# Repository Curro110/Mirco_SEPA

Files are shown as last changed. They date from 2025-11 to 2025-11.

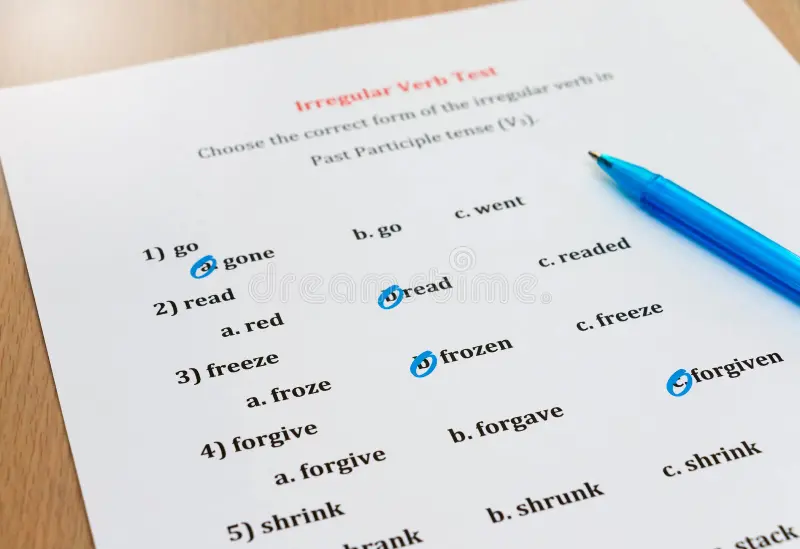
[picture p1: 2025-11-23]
Planos/examen-inglés-en-la-tabla-85873785.webp

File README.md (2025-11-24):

# Micro_SEPA Guia de instalación
Este documento explica cómo configurar el microcontrolador y la API de WhatsApp (CallMeBot) para el correcto funcionamiento del proyecto.
Siga los pasos cuidadosamente, ya que la configuración no es trivial.
1. Activación del Bot de WhatsApp
Agregue el número de teléfono +34 621 33 17 09 en sus contactos con el nombre PastilleroBot.
2.	En WhatsApp busque el contacto y escríbale ```I allow callmebot to send me messages``` esto activará el bot para que reconozca su número de teléfono.
3.	 Mandará un mensaje con una apikey a su número de teléfono el cual deberá copiar para poder configurar el programa.
4.	 Abra Arduino IDE e instale el paquete de board de ESP32 y en librerías instale también UrlEndoce de Masayuki.
5.	En esta parte de código sustituya su ssid por el nombre de su wifi y la contraseña de esta, aparte copie y pegue su apikey y ponga el número de teléfono donde recibirá los mensajes.
 ```
const char* ssid = "NOMBRE_DE_TU_WIFI";
const char* password = "CONTRASEÑA_DE_TU_WIFI";

String apiKey = "TU_API_KEY";
String phoneNumber = "34XXXXXXXXX";  // Prefijo + número, sin el símbolo +
```
Al arrancar el programa debera salir un mensaje por WhatsApp diciendo que esta conectada la esp32.

6.   Conenecte los pines del Micro alos pines de la esp32 como muestra el esquema.
   
| Micro | ESP32 |
| ----- | ----- |
| K6 | 4 |
| K7 | 5 |
| H0 | 18 |

7.  Conecte lo siguiente en el Micro:

  El BoosterPack de servos.

  La pantalla (parte superior del Micro).

  Los servos a los terminales S1, S2 y S3.

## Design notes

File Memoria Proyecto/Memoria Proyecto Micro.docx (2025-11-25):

Proyecto de Sistemas Electrónicos para Automatización (Microcontroladores)

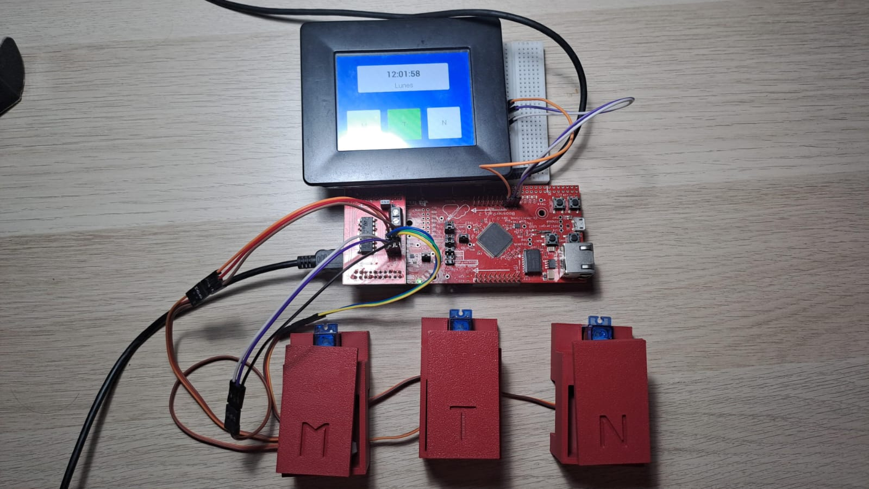
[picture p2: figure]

# 1. Introducción:

La idea central del proyecto se cimenta sobre una pregunta clave: ¿cómo se puede hacer la vida de las personas mayores más sencilla? Con el paso del tiempo, es común que las personas mayores necesiten responsables que lleven el registro de su salud. En particular la ingesta de medicamentos puede convertirse en un reto, ya sea por problemas de memoria o estado físico en general.

A partir de esta necesidad nace el proyecto de PEPA (Pastillero electrónico Programable y automático). Un proyecto diseñado para facilitar y automatizar la administración de medicamentos mediante indicadores acústicos y un sistema pastillero con servomotores. En su desarrollo se aplican los conocimientos aprendidos en las sesiones teóricas y prácticas de la asignatura, además de un exhaustivo trabajo de investigación por parte de los integrantes del proyecto.

# 2. Objetivos:

- Monitorización y registro de las pastillas tomadas en el día.
- Realización de interfaz asequible y practica para todos los públicos.
- Comunicación externa vía wifi con responsable o con propio usuario.
- Reprogramación de la toma de pastillas.
- Crear un sistema que funcione a lo largo del tiempo, siempre que esté conectado.

# 3. Enfoque Práctico

Este pastillero tiene las siguientes características:

La toma de pastillas se hará con una diferencia de 6h entre pastilla y pastilla de forma predeterminada. A no ser que el usuario programe lo contrario.

En la primera conexión del micro, se le pedirá al usuario añadir manualmente el día y hora mediante comunicación por puerto serie. Para posteriormente preguntar sobre la ingesta o no de la pastilla asignada a esa franja horaria, con el fin de llevar una monitorización desde el momento que se enciende el micro hasta que se desee apagarlo.

Avisa de cuando debe de tomar la pastilla mediante indicadores acústicos, a la hora deseada por el usuario o por la predeterminada por el programa.

Además, si se pospone la alarma y no se toma la pastilla en una franja de tiempo predeterminada, se generará un mensaje WhatsApp que avisará al mismo usuario del pastillero o a un familiar que este a cargo, la no ingesta de la pastilla.

En caso de activar tarde el micro (y por consecuente no haber registrado la toma de una pastilla) o de haber cancelado la alarma; el usuario podrá abrir manualmente la compuerta del pastillero necesario.

Al finalizar la toma de pastillas del día se ruega al usuario recargar manualmente los pastilleros mediante petición de una tecla por puerto serie, en caso contrario se saltará a este estado a una hora en concreto con el fin de poder preservar el funcionamiento del pastillero.

# 4. Resumen Programas

## 4.1 Programa de microcontrolador TIVA

Se integra una primera fase de interacción con el usuario por UART, donde se le pide rellenar la fecha y hora exacta del día. Es recomendable que esta parte sea realizada por el adulto a cargo, ya que el control del teclado puede ser enrevesada para el abuelo.

Luego, se realiza una interfaz gráfica con la FT800 donde se integran una serie de pantallas que guían de forma lógica al usuario a lo largo del proceso: pantalla de inicio, pulsadores de alarmas…

Aparte se integra una comunicación externa mediante salidas de periféricos GPIO con una ESP32 para el mensaje de WhatsApp.

## 4.2 Programa de ESP32

Se ha realizado un programa en paralelo con Arduino IDE, donde se programa la ESP32 a WIFI y el servicio de una API de WhatsApp llamada CallMeBot. Este programa realiza una primera conexión al WIFI suministrado con su SSID y su contraseña, luego una segunda conexión al servidor de la API y por último manda un mensaje WhatsApp dependiendo de las señales de entrada obtenidas por el puerto GPIO.

# 5. Realización de los programas:

## 5.1 Programa Micro

El programa implementa el control completo de un dispensador automático de pastillas con tres tomas diarias: mañana, tarde y noche. El sistema integra una pantalla táctil FT800, tres servomotores que abren cada compartimento de pastillas, y dos módulos ESP para enviar avisos o recordatorios mediante comunicación UART.

Los periféricos que se han habilitado son:

- Puerto K y H: GPIO para la comunicación con la ESP32.
- 3 módulos PWM para el mover los pastilleros mediante servos.
- UART para comunicación inicial de configuración de la fecha y marcar la recarga de las pastillas.
- Timer0 que habilita las interrupciones cada 20 ms.
- Timer1 que genera un parpadeo para las funciones de alarma.
- Pantalla FT800 inicializada mediante SPI, utilizada para dibujar la interfaz y registrar las pulsaciones táctiles de los botones.

En cuanto al funcionamiento principal del proyecto, se realiza mediante una máquina de estados switch(estado_actual):

- Inicio:

Este estado inicial pide al usuario por pantalla de introducir la fecha mediante UART. La introducción de la fecha es bastante robusta, pudiendo retroceder si el usuario se ha equivocado de carácter o incluso detectar si los caracteres introducidos no son correctos. Luego, se pasa directamente al siguiente estado de configuración.

- Dia1, Dia2, Dia3, Verificacion_dia, Hora1, Hora2, Verificacion_hora, Min1, Min2, Verificacion_min:

Esta serie continua de estados sirve para obtener mediante UART: el día de inicialización del micro, introduciendo las 3 primeras letras del día; la hora y el minuto, teniendo que añadir 2 dígitos (de 00 a 23 para la hora y de 00 a 59 para el minuto), y por último la verificación de que estos estén correctos.

Una vez introducida la hora, el programa redirecciona al usuario según la franja horaria en la que se encuentra: de 6 hasta las 12 será por la mañana, de 12 a las 18 será por la tarde y de las 18 hasta las 00 será por la noche. Esto se hace ya que el programa para inicializarse necesita saber en qué momento del día esta.

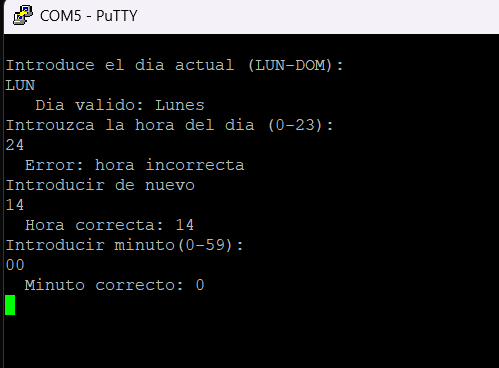
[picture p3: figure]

- Reposo1, Reposo2, Reposo3:

Como se ha explicado anteriormente, los estados de Reposo marcan si el usuario esta por la mañana, por la tarde o por la noche.

Aparte, se pregunta por pantalla si se ha tomado la pastilla que corresponde a la franja horaria en la que se encuentra el usuario.

En caso de haber tomado dicha pastilla, el usuario pasará al estado de confirmación de la hora: MananaOK, TardeOK, NocheOK.

De lo contrario, el programa redirecciona al usuario a la pantalla principal Inicio_i, donde se mostrará visualmente el pulsador de la pastilla que no se ha tomado en rojo.

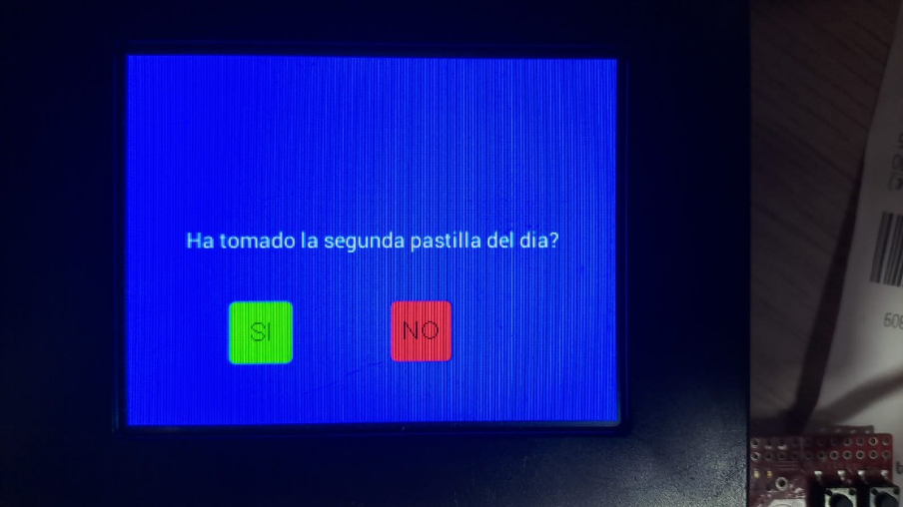
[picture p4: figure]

- MananaOK, TardeOK, NocheOK:

En este estado, se pregunta al usuario por pantalla la hora en la que se tomó la pastilla correspondiente a su franja horaria, mediante una interfaz interactiva donde el usuario puede aumentar o disminuir las horas y los minutos gracias unas flechas integradas por pantalla.

Una vez seleccionada la hora, se recalcula la toma de las siguientes pastillas (diferencia predeterminada de 6h entre pastilla y pastilla). Una vez finalizado se pasa al estado base de la interfaz llamado Inicio_i, donde se mostrará visualmente el pulsador de la pastilla que se ha tomado en verde.

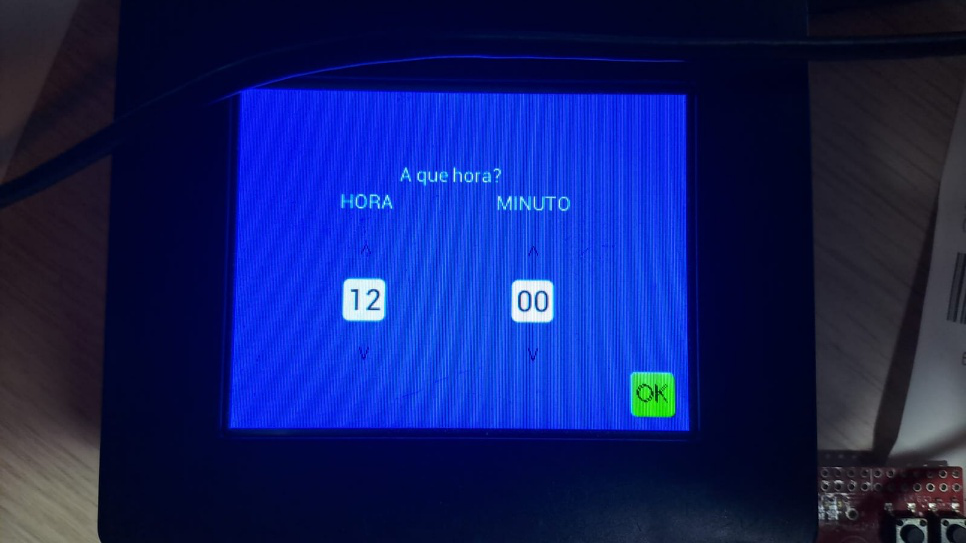
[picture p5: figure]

- Inicio_i

Este estado representa la interfaz principal del programa.

La parte superior marca el día, además de un reloj que marca el paso de las horas, minutos y segundos.

La parte inferior aparecen unos botones M, T, N que estarán de un color u otro según en qué estado se encuentre el programa: en rojo si la pastilla de esa franja horaria no se ha tomado, en verde para el caso contrario, o en blanco en caso de aun tener que programar la alarma de la pastilla correspondiente a esa franja horaria.

Si se quiere cambiar la hora programada de las pastillas o abrir el pastillero (en caso de no haber tomado la pastilla), el usuario pulsará el botón correspondiente a la franja horaria que se requiera, pasando a los estados llamados Manana, Tarde, Noche.

Si se inicia las alarmas de las pastillas, se saltará a los estados correspondientes de las alarmas: AlarmaManana, AlarmaTarde, AlarmaNoche. Las alarmas podrán saltar en cualquier momento de la interacción con la interfaz o de los siguientes estados, guardando en una variable estado_anterior el estado anterior previo a la alarma, pudiendo volver a el una vez apagada o cancelada.

Aparte este estado nos sirve de comunicación con la esp32 encendiendo los pines K6 y K7 y H1, que mandaran una señal en alto si no se ha tomado la pastilla en un tiempo preinstalado (para simplificar se ha puesto unos 10 segundos, pero podría ser perfectamente configurado).

Por último, se permite al usuario recargar el pastillero manualmente, en el caso de que la última pastilla se haya tomado (no_noche=0) y que se apriete la tecla ‘r’ o ‘R’ por puerto serie, saltando al estado Recarga. En el caso que el usuario no decida recargar, ya sea por olvido o por incapacidad, a partir de una hora predeterminada de la noche se saltará a dicho estado.

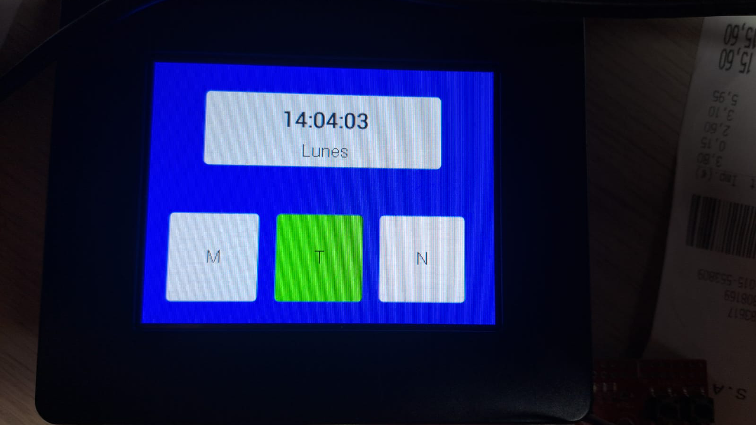
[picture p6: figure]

- Recarga, Fin_Recarga:

En este estado se permite al usuario recargar manualmente.

Se muestra tanto por pantalla como por puerto serie un aviso de recarga para el usuario, avisando de las teclas a pulsar para la debida recarga. En este caso, si se manda por UART los caracteres m, t y n, se abrirán los respectivos pastilleros, permitiendo su recarga.

Cuando el usuario plazca, puede enviar de nuevo por puerto serie la tecla f para finalizar el proceso, donde se cerrarán los pastilleros de uno en uno. Posteriormente se vuelve al estado Inicio_i, continuando con el correcto funcionamiento del programa.

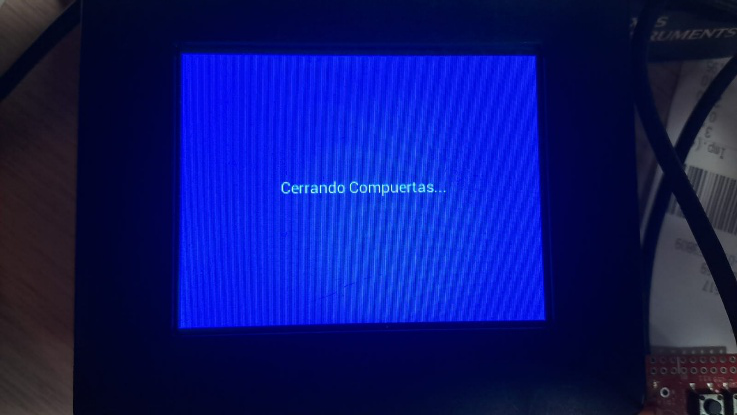
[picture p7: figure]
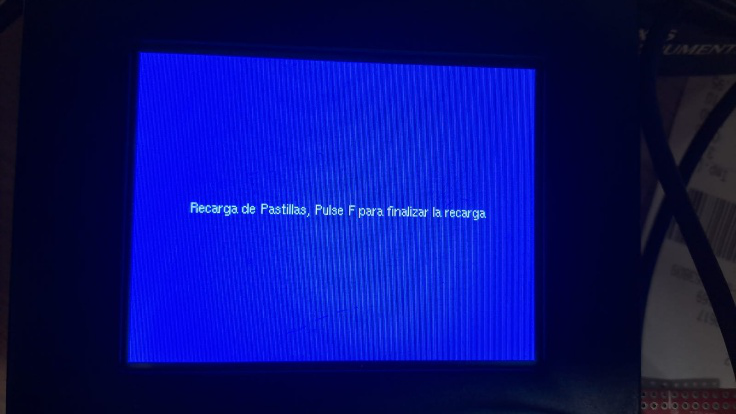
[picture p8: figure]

Este estado de interacción con el usuario es recomendable que sea realizada por el adulto a cargo, ya que puede suponer demasiado complicado para el abuelo.

- Manana,Tarde,Noche:

En estos estados se despliega una pantalla donde se muestra un botón para abrir el pastillero manualmente, un botón para editar la alarma correspondiente y un botón de cancelación en caso de querer volver a la pantalla inicial Inicio_i.

El botón para abrir manualmente el pastillero estará en gris o en verde según se deje o no abrir. Es decir, que se haya cumplido el tiempo para tomar la pastilla o que no se haya tomado en un primer momento. En caso de estar disponible se saltaría a los siguientes estados según la franja horaria en la que se encuentre el usuario: AbrirManana, AbrirTarde, AbrirNoche.

En cuanto al botón para configurar la hora de la alarma, en este se representará la hora predeterminada o programada por el usuario. En caso de querer modificar la alarma y pulsar el botón, se pasará a los siguientes estados de configuración: configHora1,2 o 3.

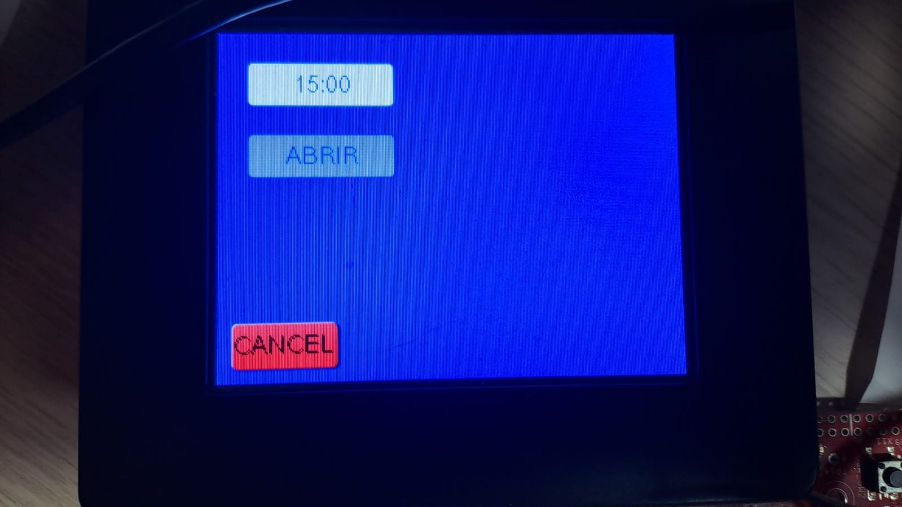
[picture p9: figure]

- AbrirManana, AbrirTarde, AbrirNoche:

Para acceder a estos estados el usuario debe:

- Haber cancelado la alarma. En ese caso, se le permite abrir manualmente la compuerta del pastillero.

-No haber tomado la pastilla correspondiente, una vez inicializado el micro.

Dentro de los estados, se abren las cajetillas mandando señales de PWM a los servos durante 5 segundos. Aparte aparece un mensaje por pantalla indicando al usuario que puede recoger su pastilla.

Una vez finalizada la recogida, se vuelve a la interfaz principal Inicio_i.

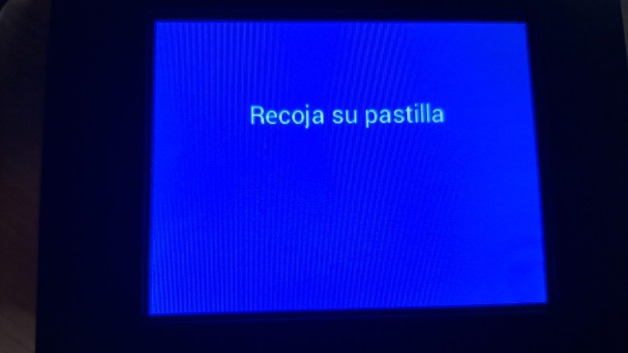
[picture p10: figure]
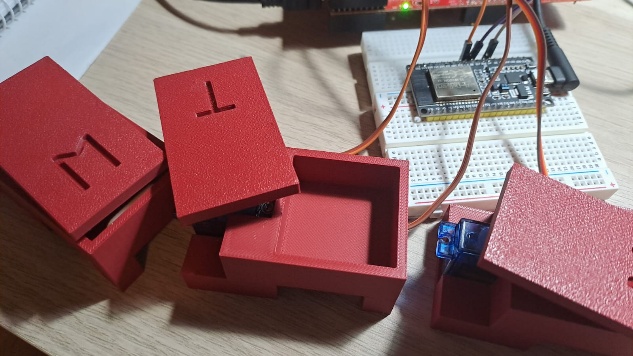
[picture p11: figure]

- ConfigHora1, ConfigHora2, ConfigHora3:

En estos estados, se despliega una pantalla en donde el usuario puede aumentar o disminuir las horas y los minutos gracias unas flechas integradas por pantalla.

No obstante, hay un rango de operación de 6 horas, es decir, el usuario no podrá programar la alarma fuera de ese rango: de 6 a 12 para la mañana, de 12 a 18 para la tarde y de 18 a 00 para la noche.

Luego de configurar o no la hora, el usuario podrá o bien cancelar (sin guardar la hora programada) o bien aceptar (guardando la hora programada), gracias a los botones de las esquinas inferiores de la pantalla. Una vez apretado alguno de los 2 botones, se volvería al estado correspondiente Manana, Tarde o Noche.

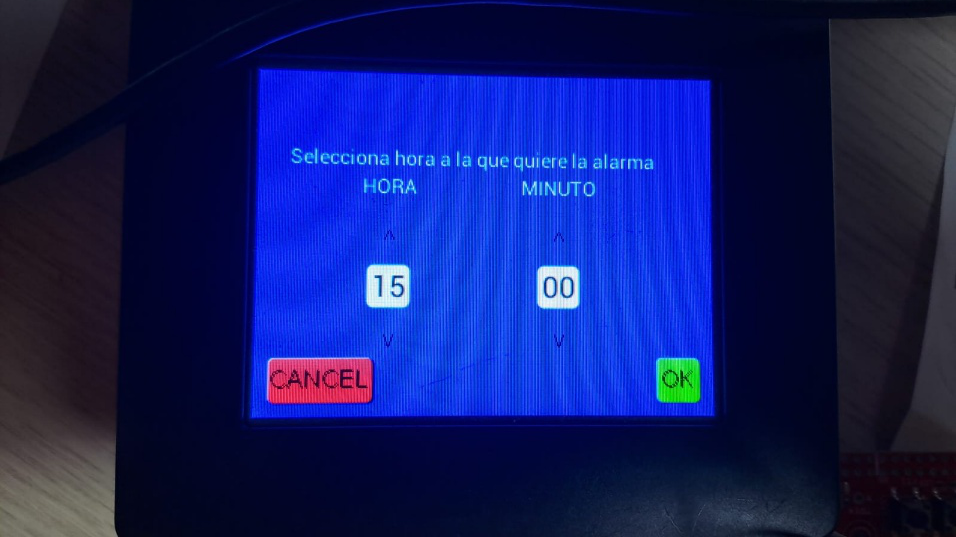
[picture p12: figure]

- AlarmaManana, AlarmaTarde, AlarmaNoche.

En estos estados se generará una alarma sonora y un parpadeo avisando de que es la hora de tomar la pastilla, además de dos botones en las esquinas inferiores de la pantalla.

La alarma sigue indefinidamente a menos que:

- El usuario apague la alarma. En cuyo caso, saltara a los estados AbrirManana, AbrirTarde, AbrirNoche, abriendo la compuerta del pastillero.

- El usuario cancela la alarma. En cuyo caso, se vuelve al estado anterior, se pone en rojo el botón correspondiente a la pastilla por tomar y se deja al usuario abrir manualmente el pastillero.

En caso de cancelar la pastilla, se inicia un temporizador con la variable tiempo_inicio, para poder contar el tiempo que pasa entre cancelar la alarma y que el usuario abra manualmente el pastillero. Como se ha comentado anteriormente, si ese tiempo fuera superior a un tiempo predeterminado, se enviaría un mensaje por WhatsApp al adulto a cargo.

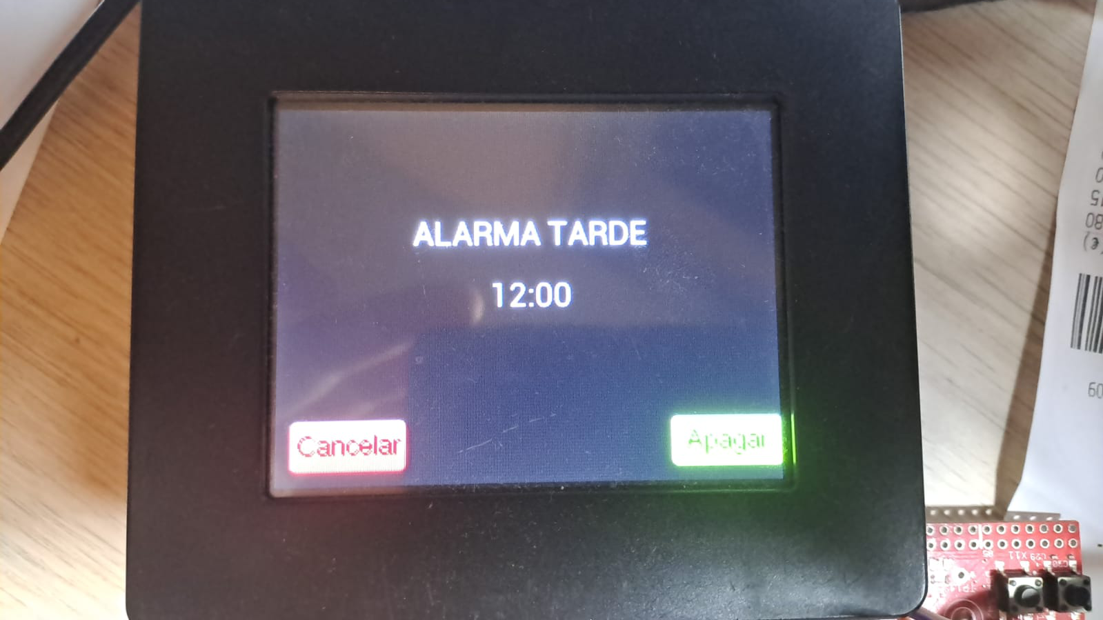
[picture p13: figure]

## 5.2 Programa ESP32:

El código implementa un sistema de notificación de toma de medicación basado en un ESP32 conectado a WiFi, que detecta la activación de tres entradas digitales correspondientes a las pastillas de la mañana, tarde y noche, enviando alertas vía WhatsApp usando el servicio CallMeBot.

Arquitectura y módulos del microcontrolador

- WiFi: Se configura con SSID y contraseña para establecer conexión a la red local, lo que permite la comunicación con el servicio CallMeBot mediante HTTP.
- GPIO: Tres pines del ESP32 (pinManana, pinTarde, pinNoche) se configuran como entradas con resistencia pull-down interna para detectar el estado de cada pastilla.
- Serial: Se utiliza para depuración y seguimiento del estado de la conexión Wifi y del envío de mensajes.

Funcionamiento principal

Inicialización (setup):

Se inicia la comunicación serie. Se configuran los pines de entrada con INPUT_PULLDOWN. Se conecta a la red Wifi, mostrando progreso por Serial. Al establecer conexión, envía un mensaje de confirmación de conexión vía WhatsApp.

Bucle principal (loop):

Se leen continuamente los estados de los pines correspondientes a cada pastilla. Se detectan cambios de estado comparando el valor actual con el valor anterior (lastManana, lastTarde, lastNoche). Si se detecta que un pin pasa de LOW a HIGH (lo que indica que la pastilla no se ha tomado), se envía un mensaje de alerta vía CallMeBot especificando la franja horaria correspondiente: mañana, tarde o noche. Se actualizan las variables de estado previo para poder detectar futuros cambios.

Comunicación con CallMeBot:

La función sendMessage() construye una URL HTTP con el número de teléfono, API key y texto codificado. Se realiza una petición POST y se comprueba el código de respuesta para confirmar el envío. Los mensajes incluyen el detalle de la pastilla que no se ha tomado, lo que permite a un cuidador recibir alertas en tiempo real.

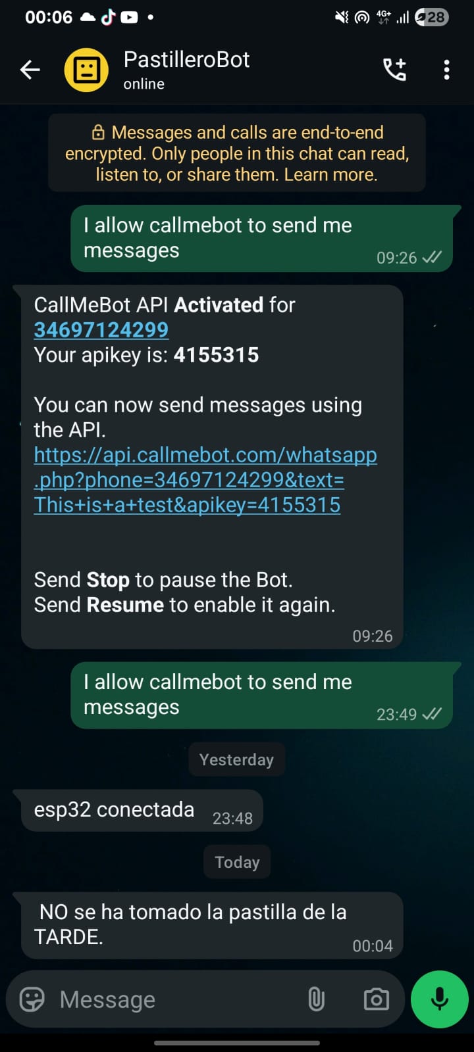
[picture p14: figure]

# Repositorio GitHub:

Se adjunta un enlace GitHub con el repositorio generado por los integrantes del grupo, donde se ven reflejadas dudas externas a la memoria como puede ser la guía de instalación para la esp32, los planos de impresión del hardware utilizado etc.

https://github.com/Curro110/Mirco_SEPA.git

# Conclusión:

El desarrollo de este proyecto ha sido fundamental para observar un problema real de la sociedad y cómo podríamos solucionarlo. Sabemos que el prototipo no es un producto que podríamos lanzar al mercado, pero nos podría sentar las bases para poder ampliar y perfeccionar funcionamientos que aseguren que un paciente se toma la pastilla y su control sea óptimo.

Queremos destacar que hemos trabajado conjuntamente para poder desarrollar este proyecto y hemos utilizado herramientas profesionales como GIT para poder mantener un seguimiento de trabajo conjunto.

Creemos firmemente que nuestro proyecto expresa los conocimientos técnicos que hemos adquirido a lo largo de la asignatura, como la intención de expandir nuestros conocimientos e integrar lo aprendido.

P.E.P.A (Pastillero Electrónico Programable Automático)

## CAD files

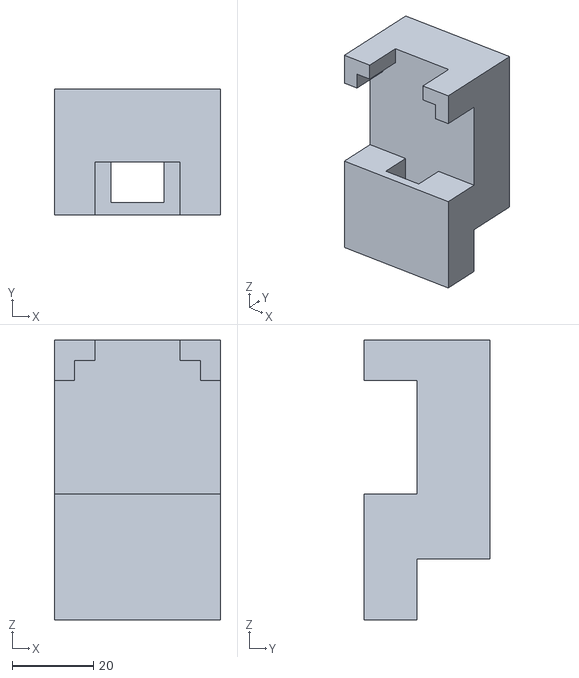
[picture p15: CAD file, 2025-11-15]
Archivos_Impresion_3D/Pastillero.stl
41.0 x 31.0 x 69.0

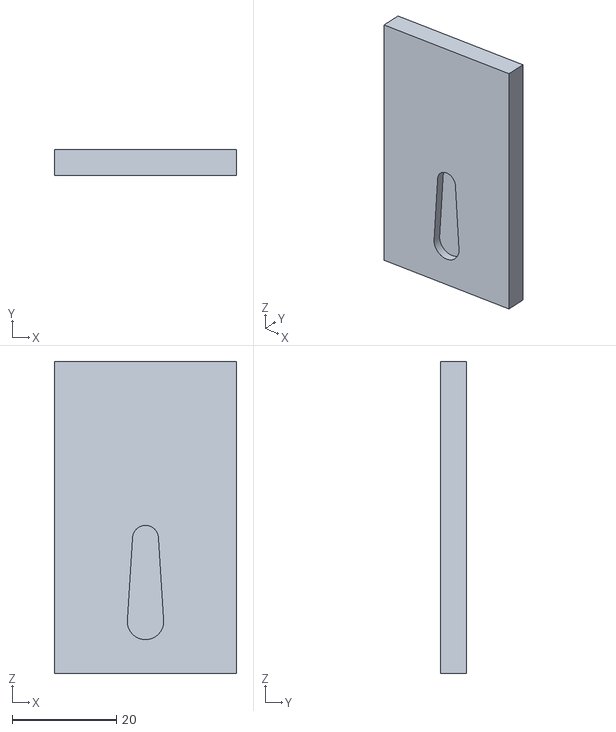
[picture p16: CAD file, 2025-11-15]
Archivos_Impresion_3D/tapa_T.stl
35.0 x 5.00 x 60.0

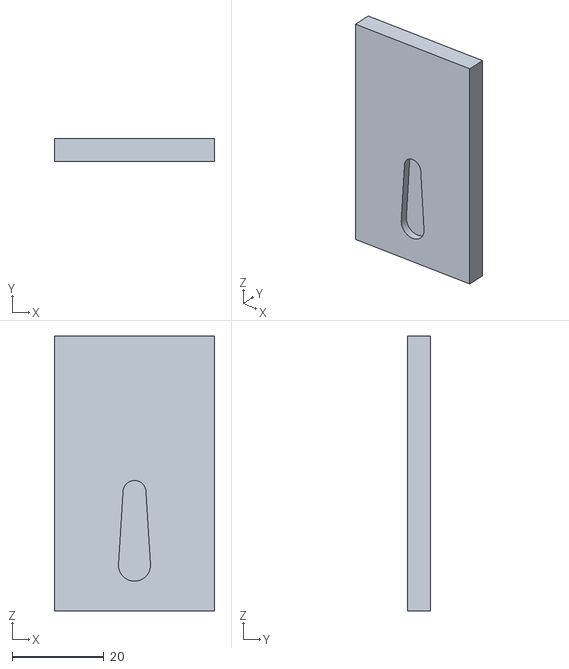
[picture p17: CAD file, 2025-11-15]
Archivos_Impresion_3D/tapa_N.stl
35.0 x 5.00 x 60.0

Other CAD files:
Archivos_Impresion_3D/tapa.stl
3D/Pastillero.f3d
3D/ServoMotor.f3d
3D/Tapa_M.f3d
3D/Tapa_N.f3d
3D/Tapa_T.f3d

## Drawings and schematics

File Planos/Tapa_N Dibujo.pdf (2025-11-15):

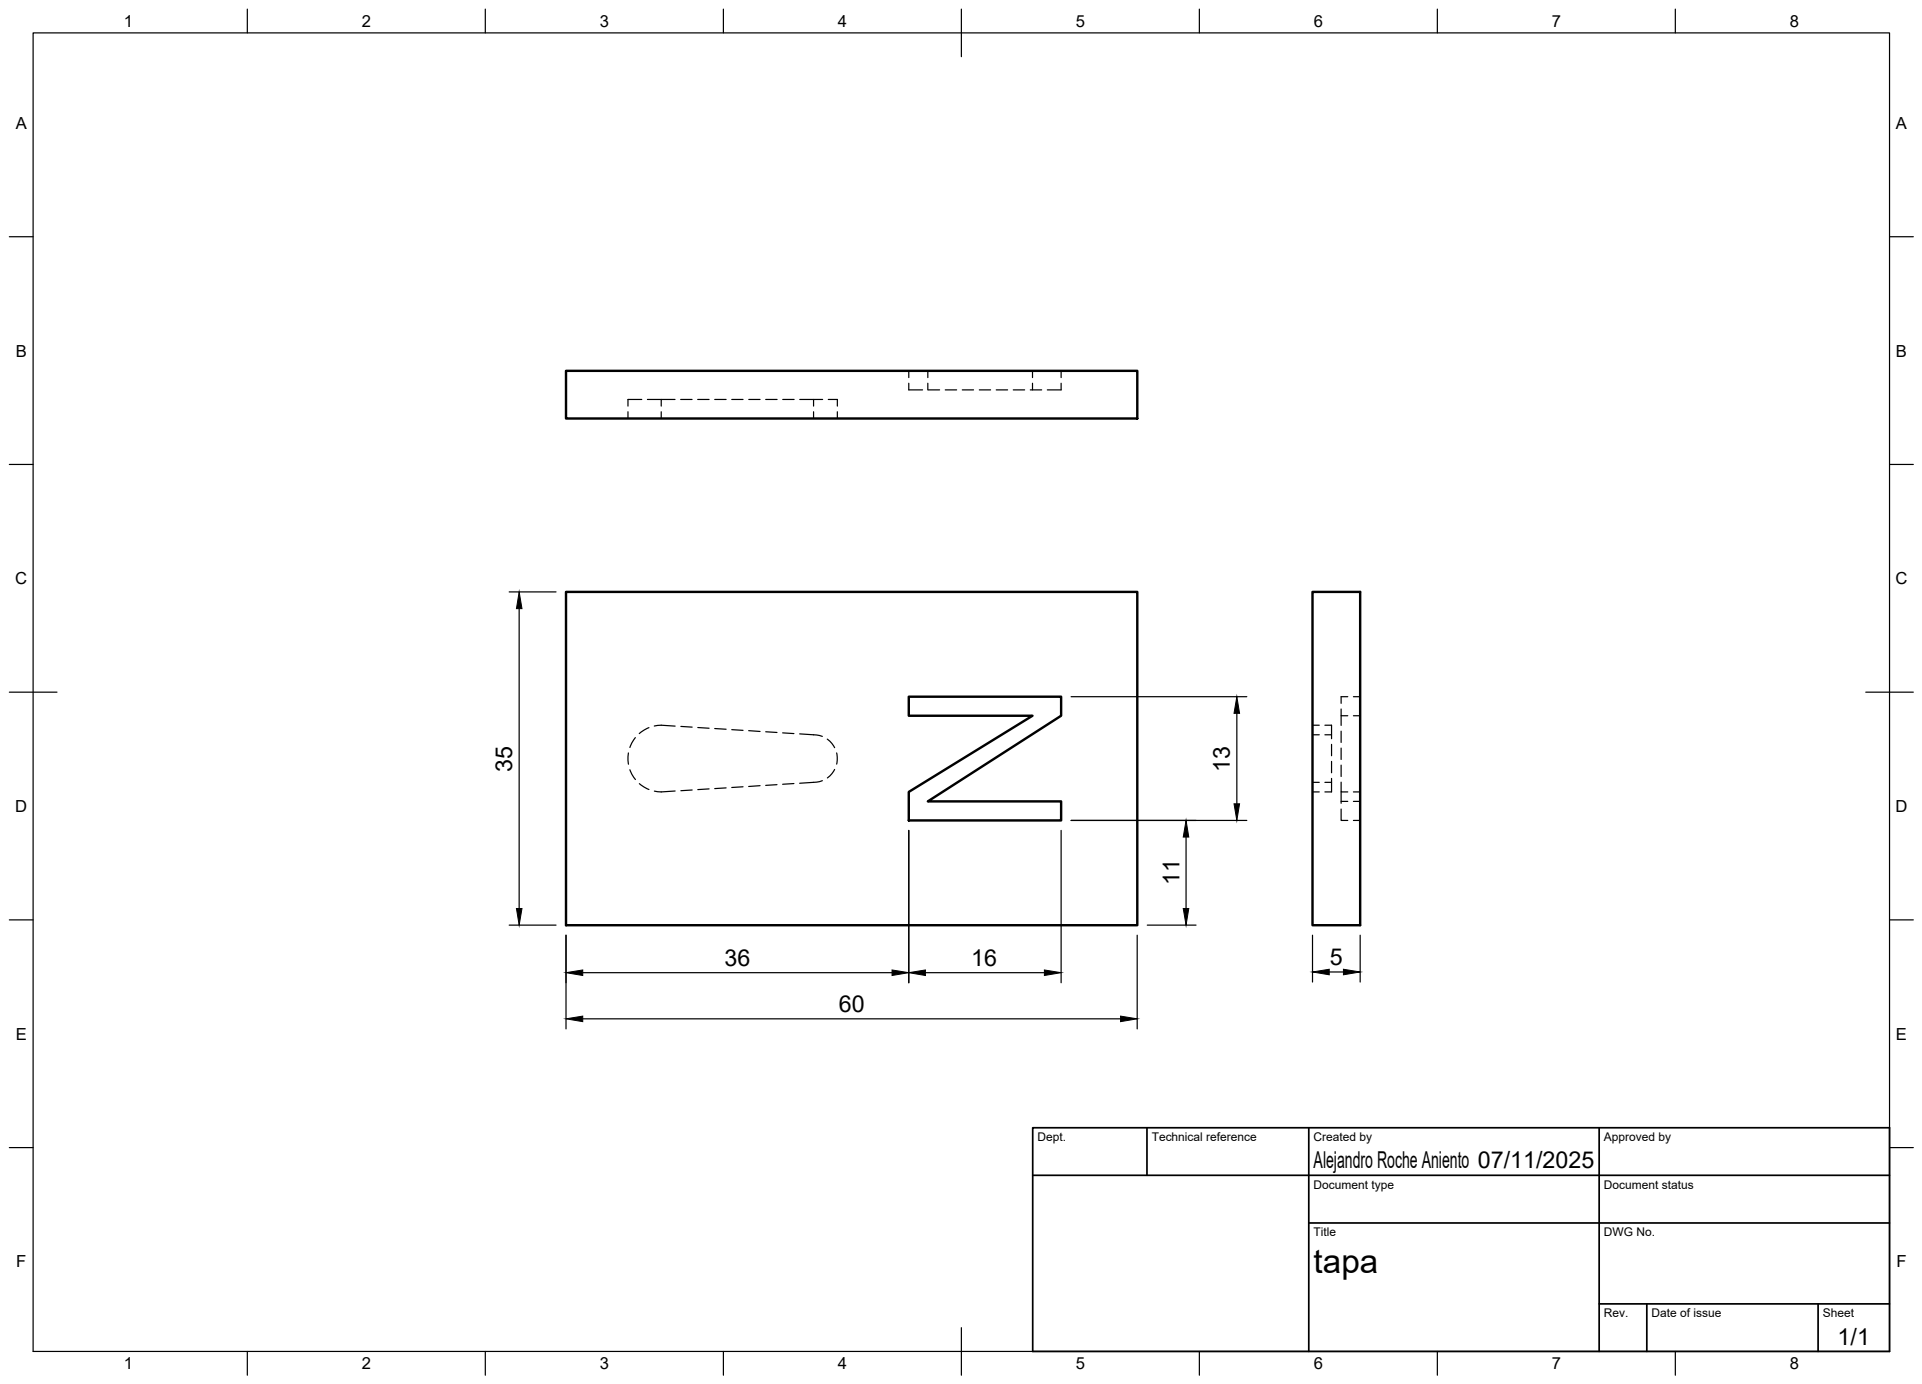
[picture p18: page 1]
Title; DWG No.; Rev.; Date of issue; Sheet

Dept. | Technical reference | Created by Alejandro Roche Aniento 07/11/2025 | Approved by

Document type | Document status

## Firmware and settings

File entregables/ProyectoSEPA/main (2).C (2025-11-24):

/*
 * main.c
 */

#include <stdint.h>
#include <stdbool.h>
#include "driverlib2.h"
#include "utils/uartstdio.h"
#include "FT800_TIVA.h"

#include <stdlib.h> // Para atoi()
#include <string.h> // Para strcmp()
#include <ctype.h>  // Para toupper()
#include <stdio.h>  // Para sprintf()

// =======================================================================
// Function Declarations
// =======================================================================
#define dword long
#define byte char

#define LED1_ON GPIOPinWrite(GPIO_PORTN_BASE, GPIO_PIN_1, GPIO_PIN_1)
#define LED1_OFF GPIOPinWrite(GPIO_PORTN_BASE, GPIO_PIN_1, 0)
#define LED2_ON GPIOPinWrite(GPIO_PORTN_BASE, GPIO_PIN_0, GPIO_PIN_0)
#define LED2_OFF GPIOPinWrite(GPIO_PORTN_BASE, GPIO_PIN_0, 0)
#define LED3_ON GPIOPinWrite(GPIO_PORTF_BASE, GPIO_PIN_4, GPIO_PIN_4)
#define LED3_OFF GPIOPinWrite(GPIO_PORTF_BASE, GPIO_PIN_4, 0)
#define LED4_ON GPIOPinWrite(GPIO_PORTF_BASE, GPIO_PIN_0, GPIO_PIN_0)
#define LED4_OFF GPIOPinWrite(GPIO_PORTF_BASE, GPIO_PIN_0, 0)

#define ESP1_ON GPIOPinWrite(GPIO_PORTK_BASE, GPIO_PIN_7, GPIO_PIN_7) // aqui estan los defines para que sea mas faciles para poner que se encienda los pines que comunican con la esp
#define ESP1_OFF GPIOPinWrite(GPIO_PORTK_BASE, GPIO_PIN_7, 0)
#define ESP2_ON GPIOPinWrite(GPIO_PORTK_BASE, GPIO_PIN_6, GPIO_PIN_6)
#define ESP2_OFF GPIOPinWrite(GPIO_PORTK_BASE, GPIO_PIN_6, 0)
#define ESP3_ON GPIOPinWrite(GPIO_PORTH_BASE, GPIO_PIN_1, GPIO_PIN_1)
#define ESP3_OFF GPIOPinWrite(GPIO_PORTK_BASE, GPIO_PIN_1, 0)

#define XpMax 300
#define XpMin 210
#define YpMax 200
#define YpMin 40

#define B1_OFF GPIOPinRead(GPIO_PORTJ_BASE, GPIO_PIN_0)
#define B1_ON !(GPIOPinRead(GPIO_PORTJ_BASE, GPIO_PIN_0))
#define B2_OFF GPIOPinRead(GPIO_PORTJ_BASE, GPIO_PIN_1)
#define B2_ON !(GPIOPinRead(GPIO_PORTJ_BASE, GPIO_PIN_1))

// #define SLEEP SysCtlSleep()
#define SLEEP SysCtlSleepFake()

unsigned int Xp = 22;

//----------------------------------Estados---------------------------------//

enum estados
{
    Inicio, // Estado en el que el usuario introduce el dia y la hora actual

    Dia1, // Se introduce primera letra del dia de la semana
    Dia2, // Se introduce segunda letra del dia de la semana
    Dia3, // Se introduce tercera letra del dia de la semana

    Hora1, // Se introduce primer digito de la hora
    Hora2, // Se introduce segundo digito de la hora

    Min1, // Se introduce primer digito de los minutos
    Min2, // Se introduce segundo digito de los minutos

    Verificacion_dia,  // Verificar si el dia es correcto
    Verificacion_hora, // Verificar si la hora es correcta
    Verificacion_min,  // Verificar si el minuto es correcto

    Reposo1, // El usuario ha tomado la pastilla de la manana?
    Reposo2, // El usuario ha tomado la pastilla de la tarde?
    Reposo3, // El usuario ha tomado la pastilla de la noche?

    MananaOK, // Se ha tomado la primera pastilla del dia
    MananaNO, // No se ha tomado la primera pastilla del dia

    TardeOK, // Se ha tomado la segunda pastilla del dia
    TardeNO, // No se ha tomado la segunda pastilla del dia

    NocheOK, // Se ha tomado la tercera pastilla del dia
    NocheNO, // No se ha tomado la tercera pastilla del dia

    Inicio_i, // Pantalla de inicio
    Recarga, // Estado de Recarga
    Fin_recarga,
    Manana,      // Pantalla para abrir manualmente el pastillero o poner alarma de la mañana
    ConfigHora1, // Pantalla para configurar la alarma de mañana
    AbrirManana, // Abrir pastillero de manera manual en caso de que no se haya tomado la pastilla

    Tarde,       // Pantalla para abrir manualmente el pastillero o poner alarma de la tarde
    ConfigHora2, // Pantalla para configurar la alarma de tarde
    AbrirTarde,  // Abrir pastillero de manera manual en caso de que no se haya tomado la pastilla

    Noche,       // Pantalla para abrir manualmente el pastillero o poner alarma de la noche
    ConfigHora3, // Pantalla para configurar la alarma de noche
    AbrirNoche,  // Abrir pastillero de manera manual en caso de que no se haya tomado la pastilla

    AlarmaManana, // Alarma de la manana suena
    AlarmaTarde,  // Alarma de la tarde suena
    AlarmaNoche   // Alarma de la noche suena
};

enum estados estado_actual, estado_anterior;

//----------------------------------Variables---------------------------------//

const char *semana[] = {"LUN", "MAR", "MIE", "JUE", "VIE", "SAB", "DOM"}; // Dias de la semana que puede introducir el usuario
char *semana_completa[] = {"Lunes", "Martes", "Miercoles", "Jueves", "Viernes", "Sabado", "Domingo"};
char dia[4];     // variable donde se registra el dia por el usuario
char hora[3];    // variable donde se registra la hora por el usuario
char minuto[3];  // variable donde se registra el minuto por el usuario
char buffer[10]; // Variable para guardar la hora en el que el usuario se ha tomado una pastilla
char reload;
char c; // variable que registra lo que guarda el usuario
int h;  // variable que registra el valor numerico de la hora introducida
int m;  // variable que registra el valor numerico del minuto introducido

int dias, horas, minutos, segundos;       // hora calculada por el micro
int horas_manana = 6, minutos_manana = 0; // variables para modificar la hora en la que se ha tomado la primera pastilla
int horas_tarde = 12, minutos_tarde = 0;  // variables para modificar la hora en la que se ha tomado la segunda pastilla
int horas_noche = 18, minutos_noche = 0;  // variables para modificar la hora en la que se ha tomado la tercera pastilla

int horas_manana_p = 6, minutos_manana_p = 0; // variables para modificar la hora en la que se ha tomado la primera pastilla al iniciar la interfaz
int horas_tarde_p = 12, minutos_tarde_p = 0;  // variables para modificar la hora en la que se ha tomado la segunda pastilla al iniciar la interfaz
int horas_noche_p = 18, minutos_noche_p = 0;  // variables para modificar la hora en la que se ha tomado la tercera pastilla al iniciar la interfaz

int minutos_tarde_ant = 0, minutos_manana_ant = 0, minutos_noche_ant = 0;
int alarma_manana = 7, alarma_tarde = 15, alarma_noche = 23;            // Alarmas predeterminadas cada 8h--> a modificar por el usuario segun la pastilla que necesite
char texto_hora_manana[10], texto_hora_tarde[10], texto_hora_noche[10]; // variable para escribir la alarma predeterminada
char buffer2[9];                                                        // Variable que imprime la hora en la pantalla
int p;                                                                  // Contador para contar segundos
int espera;                                                             // contador para esperar que el usuario coja la pastilla
int tiempo_inicio;                                                      // variable para controlar cuanto tiempo se mantiene el pastillero abierto
int tiempo_mensaje;                                                     // variable para marcar cuando se envia un mensaje por whatsapp al familiar
int infi = 0;                                                           // variable que cuenta segundos y no se reinicia
int cancel_m = 0, cancel_t = 0, cancel_n = 0;                           // Variables que se ponen a 1 en caso de que se cancele la alarma

int no_manana = 1, no_tarde = 1, no_noche = 1;               // variable que se pone a 1 si no se ha tomado la pastilla para la alarma
int pastilla_m_no = 0, pastilla_t_no = 0, pastilla_n_no = 0; // variable que se pone a 1 si no se ha tomado la pastilla para abrir la compuerta manualmente
int ultimapastilla =0 ;// variable para saber que se ha tomado la ultima pastilla y recargar se pone a 1 cuando se ha tomado la ultima pastilla y a 0 cuando entre en recarga
unsigned long REG_TT[6];
const int32_t REG_CAL[6] = {CAL_DEFAULTS};

#define NUM_SSI_DATA 3

int RELOJ, PeriodoPWM;
char led1 = 0, led2 = 0;
volatile int Flag_ints = 0;
volatile int posicion;
volatile int Max_pos = 4200; // 3750
volatile int Min_pos = 1300; // 1875
volatile int pos_100, pos_1000;
int parp = 0; // parpadeo
int Periodo_parp;

uint32_t temporizador = 0;
int m = 0;
int r_manana = 1, g_manana = 1, b_manana = 1; // variables para cambiar el color de los botones de las alarmas
int r_tarde = 1, g_tarde = 1, b_tarde = 1;    // variables para cambiar el color de los botones de las alarmas
int r_noche = 1, g_noche = 1, b_noche = 1;    // variables para cambiar el color de los botones de las alarmas

//----------------------------------Funciones---------------------------------//

// Colores//
void set_color_verde(void) { ComColor(0, 255, 0); }
void set_color_azul(void) { ComColor(0, 0, 255); }
void set_color_blanco(void) { ComColor(255, 255, 255); }
void set_color_rojo(void) { ComColor(255, 0, 0); }
void set_color_negro(void) { ComColor(0, 0, 0); }

// Funcion pra verificar el dia de la semana
int idx; // variable que guarda lo que devuelva la funcion validar_dia
int j;
int validar_dia(char *s)
{
    char tmp[4];

    tmp[0] = toupper((unsigned char)s[0]);
    tmp[1] = toupper((unsigned char)s[1]);
    tmp[2] = toupper((unsigned char)s[2]);
    tmp[3] = '\0';
    for (j = 0; j < 7; j++)
    {
        if (strcmp(tmp, semana[j]) == 0)
            return j;
    }
    return -1;
}

// Funcion para eliminar en el buffer todo lo que se haya podido escribir por UART cuando no era pedido
void flushUART(void)
{
    while (UARTCharsAvail(UART0_BASE))
        UARTCharGetNonBlocking(UART0_BASE); // descarta
}

// Funcion que sale del modo de SLEEP de forma forzada
void SysCtlSleepFake(void)
{
    while (!Flag_ints)
        ;
    Flag_ints = 0;
}

// Temporizador
void IntTimer0(void);
void IntTimer1(void);

int main(void)
{

    int i;

    RELOJ = SysCtlClockFreqSet((SYSCTL_XTAL_25MHZ | SYSCTL_OSC_MAIN | SYSCTL_USE_PLL | SYSCTL_CFG_VCO_480), 120000000);

    HAL_Init_SPI(1, RELOJ); // Boosterpack a usar, Velocidad del MC

    SysCtlPeripheralEnable(SYSCTL_PERIPH_GPION);
    GPIOPinTypeGPIOOutput(GPIO_PORTN_BASE, GPIO_PIN_0 | GPIO_PIN_1);

    // Habilitar los perifericos implicados: GPIOF, J, N
    SysCtlPeripheralEnable(SYSCTL_PERIPH_GPIOF);
    SysCtlPeripheralEnable(SYSCTL_PERIPH_GPIOG);
    SysCtlPeripheralEnable(SYSCTL_PERIPH_GPIOJ);
    SysCtlPeripheralEnable(SYSCTL_PERIPH_GPION);
    SysCtlPeripheralEnable(SYSCTL_PERIPH_GPIOK);
    SysCtlPeripheralEnable(SYSCTL_PERIPH_GPIOH);
    SysCtlPeripheralEnable(SYSCTL_PERIPH_PWM0);

    PWMClockSet(PWM0_BASE, PWM_SYSCLK_DIV_64); // al PWM le llega un reloj de 1.875MHz

    GPIOPinConfigure(GPIO_PF1_M0PWM1);
    GPIOPinConfigure(GPIO_PF2_M0PWM2);
    GPIOPinConfigure(GPIO_PF3_M0PWM3);
    GPIOPinConfigure(GPIO_PG0_M0PWM4);

    // Configurar el pin a PWM
    GPIOPinTypePWM(GPIO_PORTF_BASE, GPIO_PIN_1 | GPIO_PIN_2 | GPIO_PIN_3);
    GPIOPinTypePWM(GPIO_PORTG_BASE, GPIO_PIN_0);

    // Configurar el pwm0, contador descendente y sin sincronizacion (actualizacion automatica)
    PWMGenConfigure(PWM0_BASE, PWM_GEN_0, PWM_GEN_MODE_DOWN | PWM_GEN_MODE_NO_SYNC);
    PWMGenConfigure(PWM0_BASE, PWM_GEN_1, PWM_GEN_MODE_DOWN | PWM_GEN_MODE_NO_SYNC);
    PWMGenConfigure(PWM0_BASE, PWM_GEN_2, PWM_GEN_MODE_DOWN | PWM_GEN_MODE_NO_SYNC);

    PeriodoPWM = 37499; // 50Hz  a 1.875MHz
    posicion = Min_pos;
    Periodo_parp = 14999999; // 4 Hz
    PWMGenPeriodSet(PWM0_BASE, PWM_GEN_0, PeriodoPWM);
    PWMGenPeriodSet(PWM0_BASE, PWM_GEN_1, PeriodoPWM);
    PWMGenPeriodSet(PWM0_BASE, PWM_GEN_2, PeriodoPWM);
    // frec:50Hz
    PWMPulseWidthSet(PWM0_BASE, PWM_OUT_1, posicion); // Inicialmente, 1ms
    PWMPulseWidthSet(PWM0_BASE, PWM_OUT_2, posicion);
    PWMPulseWidthSet(PWM0_BASE, PWM_OUT_3, posicion);
    PWMPulseWidthSet(PWM0_BASE, PWM_OUT_4, posicion);

    PWMGenEnable(PWM0_BASE, PWM_GEN_0);
    PWMGenEnable(PWM0_BASE, PWM_GEN_1);
    PWMGenEnable(PWM0_BASE, PWM_GEN_2); // Habilita el generador 0

    PWMOutputState(PWM0_BASE, PWM_OUT_1_BIT | PWM_OUT_2_BIT | PWM_OUT_3_BIT | PWM_OUT_4_BIT, true); // Habilita la salida 1

    GPIOPinTypeGPIOOutput(GPIO_PORTF_BASE, GPIO_PIN_0 | GPIO_PIN_4); // F0 y F4: salidas
    GPIOPinTypeGPIOOutput(GPIO_PORTN_BASE, GPIO_PIN_0 | GPIO_PIN_1); // N0 y N1: salidas
    GPIOPinTypeGPIOInput(GPIO_PORTJ_BASE, GPIO_PIN_0 | GPIO_PIN_1);  // J0 y J1: entradas
    GPIOPadConfigSet(GPIO_PORTJ_BASE, GPIO_PIN_0 | GPIO_PIN_1, GPIO_STRENGTH_2MA, GPIO_PIN_TYPE_STD_WPU);

    GPIOPinTypeGPIOOutput(GPIO_PORTK_BASE, GPIO_PIN_7 | GPIO_PIN_6); // K6 y K7: salidas en la placa son los pines de abajo de la derecha los interirores el primero y segundo por abajo
    GPIOPinTypeGPIOOutput(GPIO_PORTH_BASE, GPIO_PIN_1);              // justo el de arriba a estos dos
    // Timer T0
    SysCtlPeripheralEnable(SYSCTL_PERIPH_TIMER0);         // Habilita T0
    TimerClockSourceSet(TIMER0_BASE, TIMER_CLOCK_SYSTEM); // T0 a 120MHz
    TimerConfigure(TIMER0_BASE, TIMER_CFG_PERIODIC);      // T0 periodico y conjunto (32b)
    TimerLoadSet(TIMER0_BASE, TIMER_A, (RELOJ / 50) - 1); // 20ms
    TimerIntRegister(TIMER0_BASE, TIMER_A, IntTimer0);
    IntEnable(INT_TIMER0A);                          // Habilitar las interrupciones globales de los timers
    TimerIntEnable(TIMER0_BASE, TIMER_TIMA_TIMEOUT); // Habilitar las interrupciones de timeout
    IntMasterEnable();                               // Habilitacion global de interrupciones
    TimerEnable(TIMER0_BASE, TIMER_A);               // Habilitar Timer0

    // Timer 1
    SysCtlPeripheralEnable(SYSCTL_PERIPH_TIMER1);         // Habilita T1
    TimerClockSourceSet(TIMER1_BASE, TIMER_CLOCK_SYSTEM); // T1 a 120MHz
    TimerConfigure(TIMER1_BASE, TIMER_CFG_PERIODIC);      // T1 periodico y conjunto (32b)
    TimerLoadSet(TIMER1_BASE, TIMER_A, Periodo_parp);     // 125 ms
    TimerIntRegister(TIMER1_BASE, TIMER_A, IntTimer1);
    IntEnable(INT_TIMER1A);                          // Habilitar las interrupciones globales de los timers
    TimerIntEnable(TIMER1_BASE, TIMER_TIMA_TIMEOUT); // Habilitar las interrupciones de timeout
    IntMasterEnable();                               // Habilitacion global de interrupciones
    TimerEnable(TIMER1_BASE, TIMER_A);               // Habilitar Timer1

    // Habilitar UART
    SysCtlPeripheralEnable(SYSCTL_PERIPH_GPIOA);
    SysCtlPeripheralEnable(SYSCTL_PERIPH_UART0);
    GPIOPinConfigure(GPIO_PA0_U0RX);
    GPIOPinConfigure(GPIO_PA1_U0TX);
    GPIOPinTypeUART(GPIO_PORTA_BASE, GPIO_PIN_0 | GPIO_PIN_1);

    UARTStdioConfig(0, 115200, RELOJ);

    SysCtlPeripheralSleepEnable(SYSCTL_PERIPH_GPIOK);
    SysCtlPeripheralSleepEnable(SYSCTL_PERIPH_GPIOH); // estas dos lineas de codigo habilita las salidas a la esp
    SysCtlPeripheralSleepEnable(SYSCTL_PERIPH_GPIOJ);
    SysCtlPeripheralSleepEnable(SYSCTL_PERIPH_TIMER0); // Habilita T0
    SysCtlPeripheralSleepEnable(SYSCTL_PERIPH_TIMER1); // Habilita T1
    SysCtlPeripheralSleepEnable(SYSCTL_PERIPH_GPIOF);
    SysCtlPeripheralSleepEnable(SYSCTL_PERIPH_GPION);
    SysCtlPeripheralSleepEnable(SYSCTL_PERIPH_PWM0);

    SysCtlPeripheralClockGating(true);

    Inicia_pantalla();
    // Note: Keep SPI below 11MHz here

    // =======================================================================
    // Delay before we begin to display anything
    // =======================================================================

    SysCtlDelay(RELOJ / 3);

    for (i = 0; i < 6; i++)
        Esc_Reg(REG_TOUCH_TRANSFORM_A + 4 * i, REG_CAL[i]);

    estado_actual = Inicio;

    while (1)
    {
        SLEEP;

        switch (estado_actual)
        {

        case Inicio:
            // Se debe primero introducir el dia y la hora correcta
            Nueva_pantalla(0x10, 0x10, 0x10);

            // FONDO
            set_color_azul();
            ComRect(0, 0, HSIZE, VSIZE, true);
            set_color_blanco();
            ComTXT(HSIZE / 2, VSIZE / 2, 26, OPT_CENTER, "Introduce Dia, Hora y Minuto en el ordenador");

            Dibuja();

            UARTprintf("\nIntroduce el dia actual (LUN-DOM): \n");
            flushUART(); // descartamos input previo
            estado_actual = Dia1;

            break;

            //--------------------------------------Usuario introduce dia-----------------------------------------------//

        case Dia1:

            if (UARTCharsAvail(UART0_BASE))
            {
                c = UARTCharGetNonBlocking(UART0_BASE);
                dia[0] = c;
                UARTCharPutNonBlocking(UART0_BASE, c);
                estado_actual = Dia2;
            }

            break;

        case Dia2:
            if (UARTCharsAvail(UART0_BASE))
            {
                c = UARTCharGetNonBlocking(UART0_BASE);
                if (c == 0x08)
                {
                    // borrar el caracter anterior
                    dia[0] = '\0';
                    UARTprintf("\b \b"); // borrar en pantalla
                    estado_actual = Dia1;
                }
                else
                {
                    dia[1] = c;
                    UARTCharPutNonBlocking(UART0_BASE, c);
                    estado_actual = Dia3;
                }
            }

            break;

        case Dia3:
            if (UARTCharsAvail(UART0_BASE))
            {
                c = UARTCharGetNonBlocking(UART0_BASE);
                if (c == 0x08)
                {
                    dia[1] = '\0';
                    UARTprintf("\b \b");
                    estado_actual = Dia2;
                }
                else
                {
                    dia[2] = c;
                    dia[3] = '\0';
                    UARTCharPutNonBlocking(UART0_BASE, c);
                    UARTCharPut(UART0_BASE, '\n');
                    estado_actual = Verificacion_dia;
                }
            }

            break;

        case Verificacion_dia:
            idx = validar_dia(dia);
            if (idx >= 0)
            { // dia correcto

                UARTprintf("Dia valido: %s\n", semana_completa[idx]);
                UARTprintf("Introuzca la hora del dia (0-23):\n");
                estado_actual = Hora1;
            }
            else
            { // dia no valido

                UARTprintf("Error: dia no valido (se recibio '%c%c%c')\n", dia[0], dia[1], dia[2]);
                UARTprintf("Introducir de nuevo\n");
                estado_actual = Inicio;
            }
            break;

            //--------------------------------------Usuario introduce hora-----------------------------------------------//

        case Hora1:
            if (UARTCharsAvail(UART0_BASE))
            {
                c = UARTCharGetNonBlocking(UART0_BASE);
                if (c == 0x08)
                {
                    // No hay nada que borrar
                }
                else if (c >= '0' && c <= '9')
                {
                    hora[0] = c;
                    UARTCharPutNonBlocking(UART0_BASE, c);
                    estado_actual = Hora2;
                }
                else
                {
                    UARTprintf("Error: solo se permiten números.\n");
                    UARTprintf("Introducir de nuevo:\n");
                    estado_actual = Hora1;
                }
            }
            break;

        case Hora2:
            if (UARTCharsAvail(UART0_BASE))
            {
                c = UARTCharGetNonBlocking(UART0_BASE);

                if (c == 0x08)
                {
                    // Borrar primer dígito
                    hora[0] = '\0';
                    UARTprintf("\b \b");
                    estado_actual = Hora1;
                }
                else if (c >= '0' && c <= '9')
                {
                    hora[1] = c;
                    hora[2] = '\0';
                    UARTCharPutNonBlocking(UART0_BASE, c);
                    UARTCharPut(UART0_BASE, '\n');
                    estado_actual = Verificacion_hora;
                }
                else
                {
                    UARTprintf("Error: solo se permiten números.\n");
                    UARTprintf("Introducir de nuevo:\n");
                    estado_actual = Hora1;
                }
            }
            break;

        case Verificacion_hora:
            h = atoi(hora); // se convierte texto a entero

            if (h >= 0 && h <= 23)
            {
                UARTprintf("Hora correcta: %d\n", h);
                UARTprintf("Introducir minuto(0-59): \n");
                horas = h;
                estado_actual = Min1; // siguiente paso
            }
            else
            {
                UARTprintf("Error: hora incorrecta\n");
                UARTprintf("Introducir de nuevo\n");
                estado_actual = Hora1;
            }

            break;

            //--------------------------------------Usuario introduce minutos-----------------------------------------------//

        case Min1:
            if (UARTCharsAvail(UART0_BASE))
            {
                c = UARTCharGetNonBlocking(UART0_BASE);

                if (c == 0x08)
                {
                    // No hay nada que borrar aquí
                }
                else if (c >= '0' && c <= '9')
                {
                    minuto[0] = c;
                    UARTCharPutNonBlocking(UART0_BASE, c);
                    estado_actual = Min2;
                }
                else
                {
                    UARTprintf("Error: solo se permiten numeros.\n");
                    UARTprintf("Introducir de nuevo:\n");
                    estado_actual = Min1;
                }
            }
            break;
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

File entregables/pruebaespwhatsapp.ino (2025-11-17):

#include <WiFi.h>
#include <HTTPClient.h>
#include <WiFiClient.h>
#include <UrlEncode.h>

// ====== CONFIGURACIÓN WIFI ======
const char* ssid = "REPLACE_WITH_YOUR_SSID";
const char* password = "REPLACE_WITH_YOUR_PASSWORD";

// ====== CONFIGURACIÓN CALLMEBOT ======
String phoneNumber = "+34XXXXXXXXX"; 
String apiKey = "REPLACE_WITH_YOUR_API_KEY";

// ====== PINES DE ENTRADA ======
const int pinManana = 4;     // GPIO para pastilla de la mañana
const int pinTarde  = 5;     // GPIO para pastilla de la tarde
const int pinNoche  = 18;    // GPIO para pastilla de la noche

// Variables para recordar último estado
bool lastManana = LOW;
bool lastTarde  = LOW;
bool lastNoche  = LOW;

// ====== FUNCIÓN PARA ENVIAR WHATSAPP ======
void sendMessage(String message){
  String url = "http://api.callmebot.com/whatsapp.php?phone=" 
                + phoneNumber + "&apikey=" + apiKey 
                + "&text=" + urlEncode(message);

  WiFiClient client;    
  HTTPClient http;
  http.begin(client, url);
  http.addHeader("Content-Type", "application/x-www-form-urlencoded");

  int httpResponseCode = http.POST(url);

  if (httpResponseCode == 200){
    Serial.println("Mensaje enviado: " + message);
  } else {
    Serial.print("Error: ");
    Serial.println(httpResponseCode);
  }

  http.end();
}

// ====== INICIO ======
void setup() {
  Serial.begin(115200);

  pinMode(pinManana, INPUT);
  pinMode(pinTarde, INPUT);
  pinMode(pinNoche, INPUT);

  WiFi.begin(ssid, password);
  Serial.print("Conectando a WiFi");

  while(WiFi.status() != WL_CONNECTED) {
    delay(500);
    Serial.print(".");
  }

  Serial.println("\nConectado. IP:");
  Serial.println(WiFi.localIP());
}

// ====== LOOP PRINCIPAL ======
void loop() {
  // Leer los pines
  bool estadoManana = digitalRead(pinManana);
  bool estadoTarde  = digitalRead(pinTarde);
  bool estadoNoche  = digitalRead(pinNoche);

  // ---- DETECCIÓN DE CAMBIOS ----
  
  if (estadoManana == HIGH && lastManana == LOW) {
    sendMessage(" NO se ha tomado la pastilla de la MAÑANA.");
    delay(2000);
  }

  if (estadoTarde == HIGH && lastTarde == LOW) {
    sendMessage(" NO se ha tomado la pastilla de la TARDE.");
    delay(2000);
  }

  if (estadoNoche == HIGH && lastNoche == LOW) {
    sendMessage(" NO se ha tomado la pastilla de la NOCHE.");
    delay(2000);
  }

  // Guardar estados previos
  lastManana = estadoManana;
  lastTarde  = estadoTarde;
  lastNoche  = estadoNoche;
}

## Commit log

2025-10-21 carpeta con las driverlibs uart etc
    aqui vamos a meter esa carpeta en el workspace y vamos a modificarla directamente
2025-11-07 Agrego los archivos de las figuras 3D
    [Pastillero.f3d, ServoMotor.f3d, Tapa.f3d]
2025-11-07 Agrego planos pdf de las figuras 3D
2025-11-10 cambio en el main
2025-11-12 añadido para conexion con la esp32
2025-11-12 Cambios en el código
2025-11-15 Añado 3D
    [Pastillero.f3d, Pastillero.stl, Tapa_M.f3d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]
2025-11-18 Datasheet Servo
2025-11-22 añadida la memoria
2025-11-23 cambios para el servo
2025-11-23 cambios finales de la memoria
2025-11-23 Update README with installation instructions
    Added installation guide for Micro_SEPA project, including WhatsApp bot activation and ESP32 setup instructions.
2025-11-24 cambios añadiendo estado de recarga
2025-11-24 cambio en el read me
    Updated instructions for activating the WhatsApp bot and configuring the ESP32.
